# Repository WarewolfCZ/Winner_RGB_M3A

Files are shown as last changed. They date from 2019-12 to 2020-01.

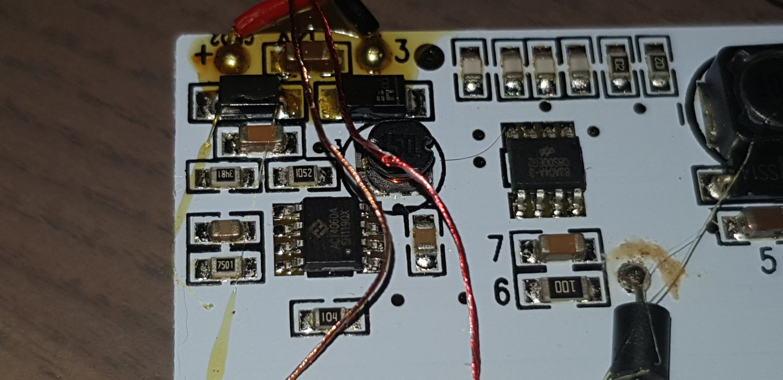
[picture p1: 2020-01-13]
Photo/20191224_005346.jpg

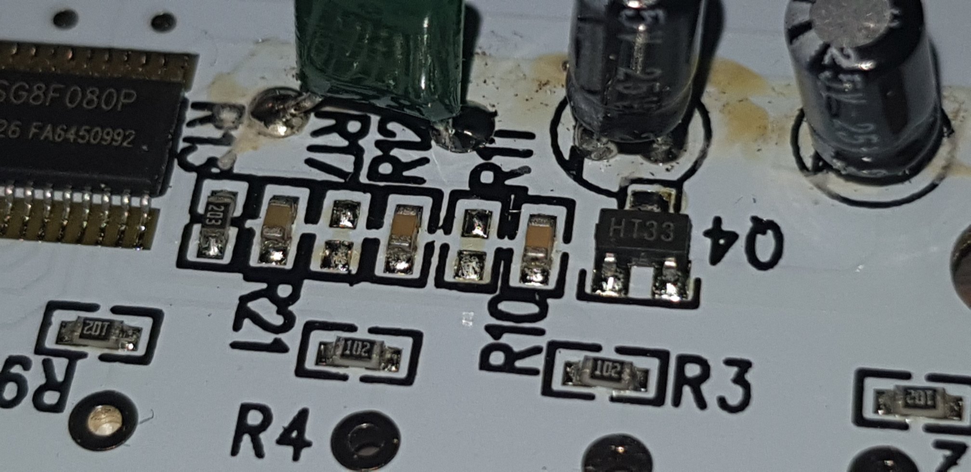
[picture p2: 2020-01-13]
Photo/20191223_173658.jpg

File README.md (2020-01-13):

# Winner_RGB_M3A MOD

This mod board reads lamp status and stores it in EEPROM. When the power is turned off and back on, it is restored to stored state.

## Serial port 

Serial port communication is configured to 19200 baud/s, 8 data bits, even parity

## Protocol

Mod board can be controlled via serial connection/bluetooth. Commands are separated by new line character &lt;CR&gt; or &lt;LF&gt;

### SET

Set lamp state - turn on/off, dim, change light temperature. If cold_level &gt; 0 and warm_level &gt; 0, the cold_level has to be equal to warm_level. 

  SET&lt;COLD_LEVEL&gt;&lt;WARM_LEVEL&gt;

&lt;COLD_LEVEL&gt; = number 0 to 5
&lt;WARM_LEVEL&gt; = number 0 to 5

Example:

  SET11

Response:

  SET_OK:11

### PIN

Set bluetooth pin

  PIN&lt;pin_code&gt;

&lt;pin_code&gt; = 4 digit code

Example:

  PIN0000
  
Response:

  PIN_OK:0000

### STATUS

Get lamp status - light levels

Example:

  STATUS

Response:

  STATUS:&lt;INPUT1&gt;,&lt;INPUT2&gt;,&lt;COLD_LEVEL&gt;,&lt;WARM_LEVEL&gt;,&lt;EEPROM_COLD_LEVEL&gt;,&lt;EEPROM_WARM_LEVEL&gt;

&lt;INPUT1&gt; = value from A/D converter
&lt;INPUT2&gt; = value from A/D converter
&lt;COLD_LEVEL&gt; = number 0 to 5
&lt;WARM_LEVEL&gt; = number 0 to 5
&lt;EEPROM_COLD_LEVEL&gt; = number 0 to 5
&lt;EEPROM_WARM_LEVEL&gt; = number 0 to 5
  
Response example:

  STATUS:0,312,0,2,0,2
  
### DEBUG

Toggle debug mode

Example:

  DEBUG

Response:

  DEBUG_OK

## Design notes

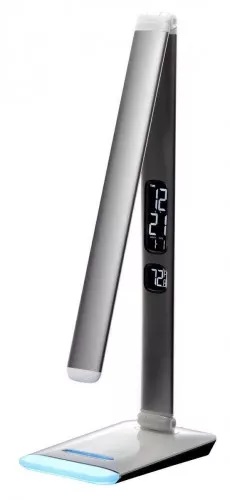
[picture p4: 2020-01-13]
Photo/lamp-led-rgb-m3a.jpg

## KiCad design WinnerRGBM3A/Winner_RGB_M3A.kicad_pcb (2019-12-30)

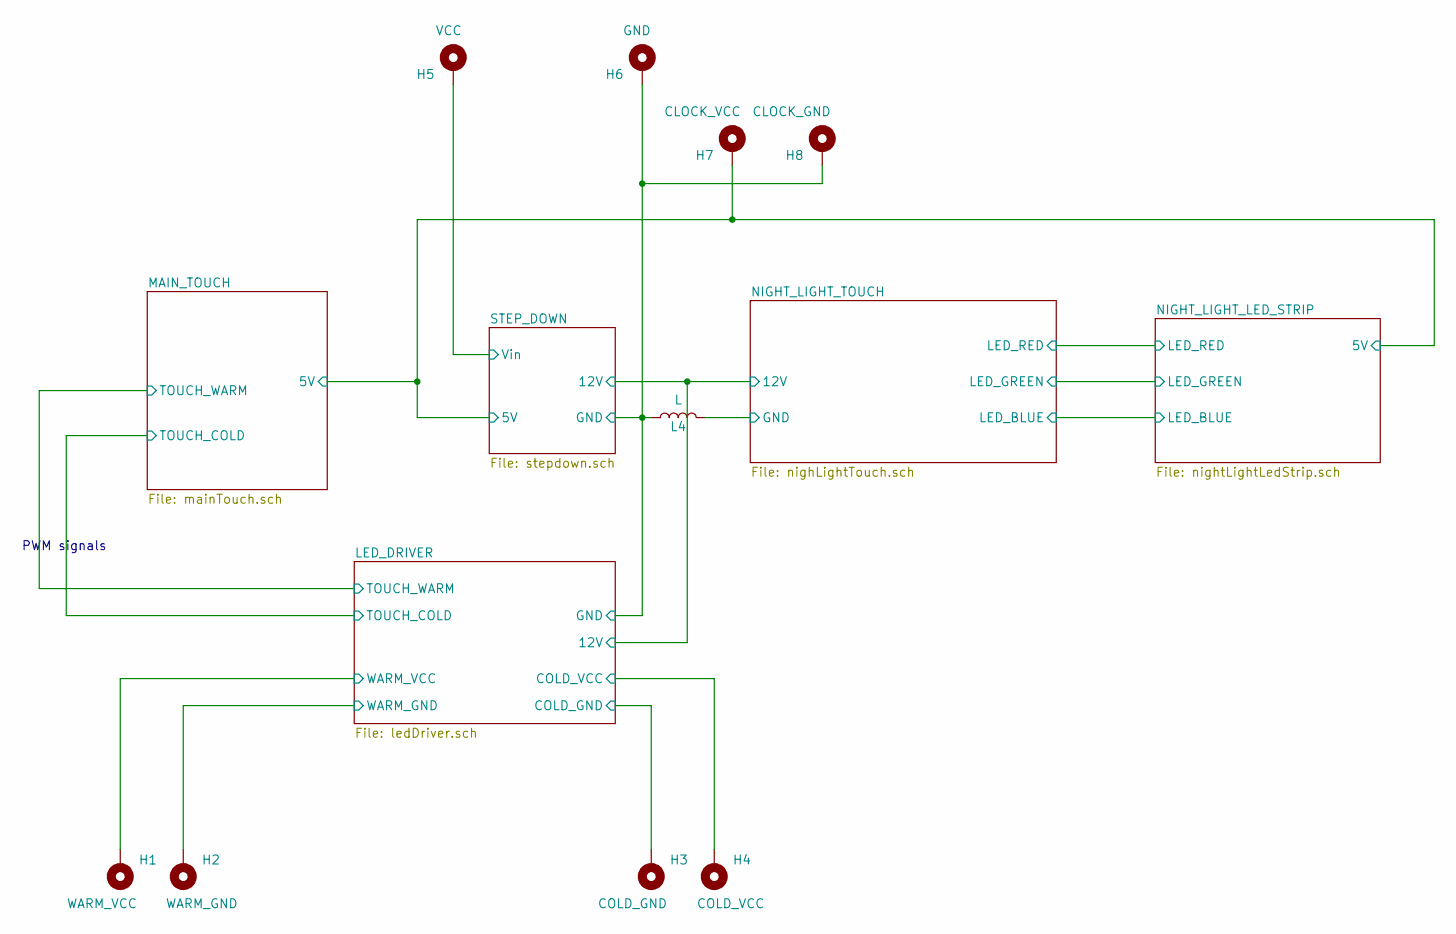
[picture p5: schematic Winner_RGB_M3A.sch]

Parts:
H1: WARM_VCC; Pin_D1.0mm_L10.0mm
H2: WARM_GND; Pin_D1.0mm_L10.0mm
H3: COLD_GND; Pin_D1.0mm_L10.0mm
H4: COLD_VCC; Pin_D1.0mm_L10.0mm
H5: VCC; Pin_D1.0mm_L10.0mm
H6: GND; Pin_D1.0mm_L10.0mm
H7: CLOCK_VCC; Pin_D1.0mm_L10.0mm
H8: CLOCK_GND; Pin_D1.0mm_L10.0mm
L4: L; L_Axial_L14.0mm_D4.5mm_P15.24mm_Horizontal_Fastron_LACC

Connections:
/LED_DRIVER/COLD_GND: H3.1; also elsewhere on the board
/LED_DRIVER/COLD_VCC: H4.1; also elsewhere on the board
/LED_DRIVER/WARM_GND: H2.1; also elsewhere on the board
/LED_DRIVER/WARM_VCC: H1.1; also elsewhere on the board
/MAIN_TOUCH/5V: H7.1; also elsewhere on the board
/NIGHT_LIGHT_TOUCH/GND: L4.2; also elsewhere on the board
/STEP_DOWN/Vin: H5.1; also elsewhere on the board
GNDPWR: H6.1, H8.1, L4.1; also elsewhere on the board

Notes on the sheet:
PWM signals

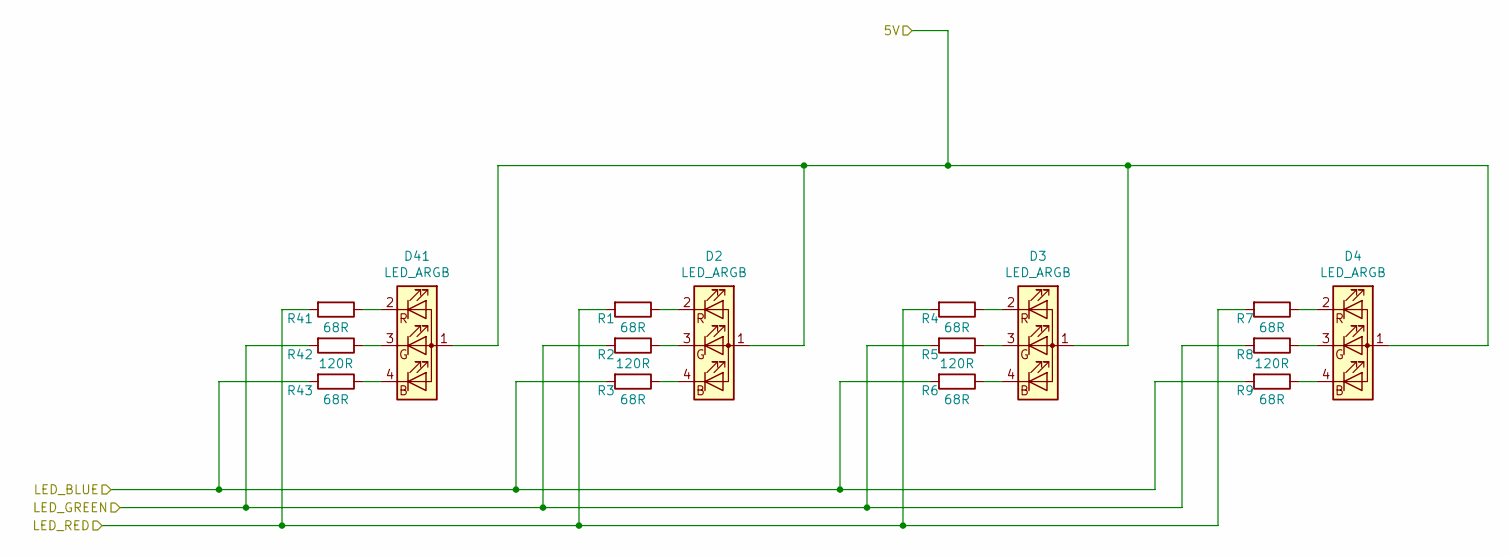
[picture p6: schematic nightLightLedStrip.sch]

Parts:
D2, D3, D4, D41: LED_ARGB; LED_WS2812_PLCC6_5.0x5.0mm_P1.6mm
R1, R3, R4, R6, R7, R9, R41, R43: 68R; R_0805_2012Metric
R2, R5, R8, R42: 120R; R_0805_2012Metric

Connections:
/MAIN_TOUCH/5V: D2.1 (A), D3.1 (A), D4.1 (A), D41.1 (A); also elsewhere on the board
/NIGHT_LIGHT_LED_STRIP/LED_BLUE: R3.2, R6.2, R9.2, R43.2; also elsewhere on the board
/NIGHT_LIGHT_LED_STRIP/LED_GREEN: R2.2, R5.2, R8.2, R42.2; also elsewhere on the board
/NIGHT_LIGHT_LED_STRIP/LED_RED: R1.2, R4.2, R7.2, R41.2; also elsewhere on the board
unnamed: D2.2 (RK), R1.1
unnamed: D2.3 (GK), R2.1
unnamed: D2.4 (BK), R3.1
unnamed: D3.2 (RK), R4.1
unnamed: D3.3 (GK), R5.1
unnamed: D3.4 (BK), R6.1
unnamed: D4.2 (RK), R7.1
unnamed: D4.3 (GK), R8.1
unnamed: D4.4 (BK), R9.1
unnamed: D41.2 (RK), R41.1
unnamed: D41.3 (GK), R42.1
unnamed: D41.4 (BK), R43.1

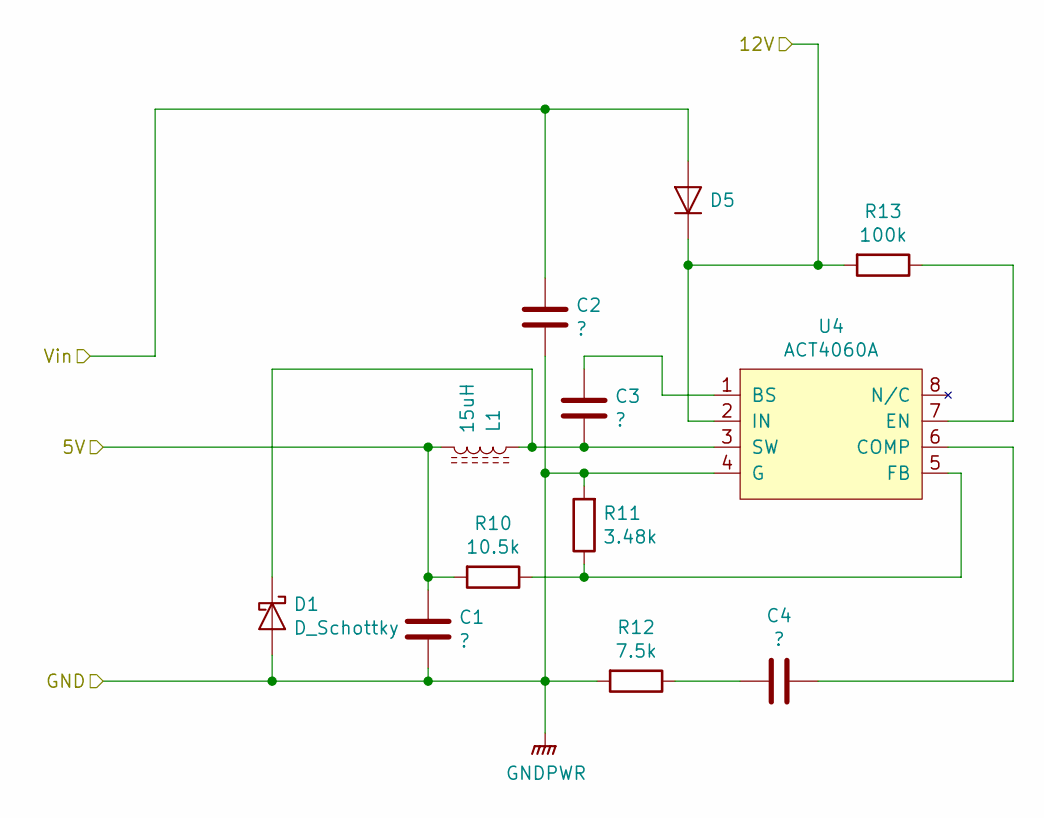
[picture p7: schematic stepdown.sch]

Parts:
C1: ?; C_1206_3216Metric
C2: ?; C_1210_3225Metric
C3, C4: ?; C_0805_2012Metric
D1: D_Schottky; D_2010_5025Metric
D5: D; D_2010_5025Metric
L1: 15uH; L_Wuerth_HCI-5040
R10: 10.5k; R_0805_2012Metric
R11: 3.48k; R_0805_2012Metric
R12: 7.5k; R_0805_2012Metric
R13: 100k; R_0805_2012Metric
U4: ACT4060A; SOP-8_3.76x4.96mm_P1.27mm

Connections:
/LED_DRIVER/12V: D5.1 (K), R13.2, U4.2 (IN); also elsewhere on the board
/MAIN_TOUCH/5V: C1.1, L1.2, R10.2; also elsewhere on the board
/STEP_DOWN/Vin: C2.1, D5.2 (A); also elsewhere on the board
GNDPWR: C1.2, C2.2, D1.2 (A), R11.2, R12.2, U4.4 (G); also elsewhere on the board
unnamed: C3.1, U4.1 (BS)
unnamed: C3.2, D1.1 (K), L1.1, U4.3 (SW)
unnamed: C4.1, U4.6 (COMP)
unnamed: C4.2, R12.1
unnamed: R10.1, R11.1, U4.5 (FB)
unnamed: R13.1, U4.7 (EN)

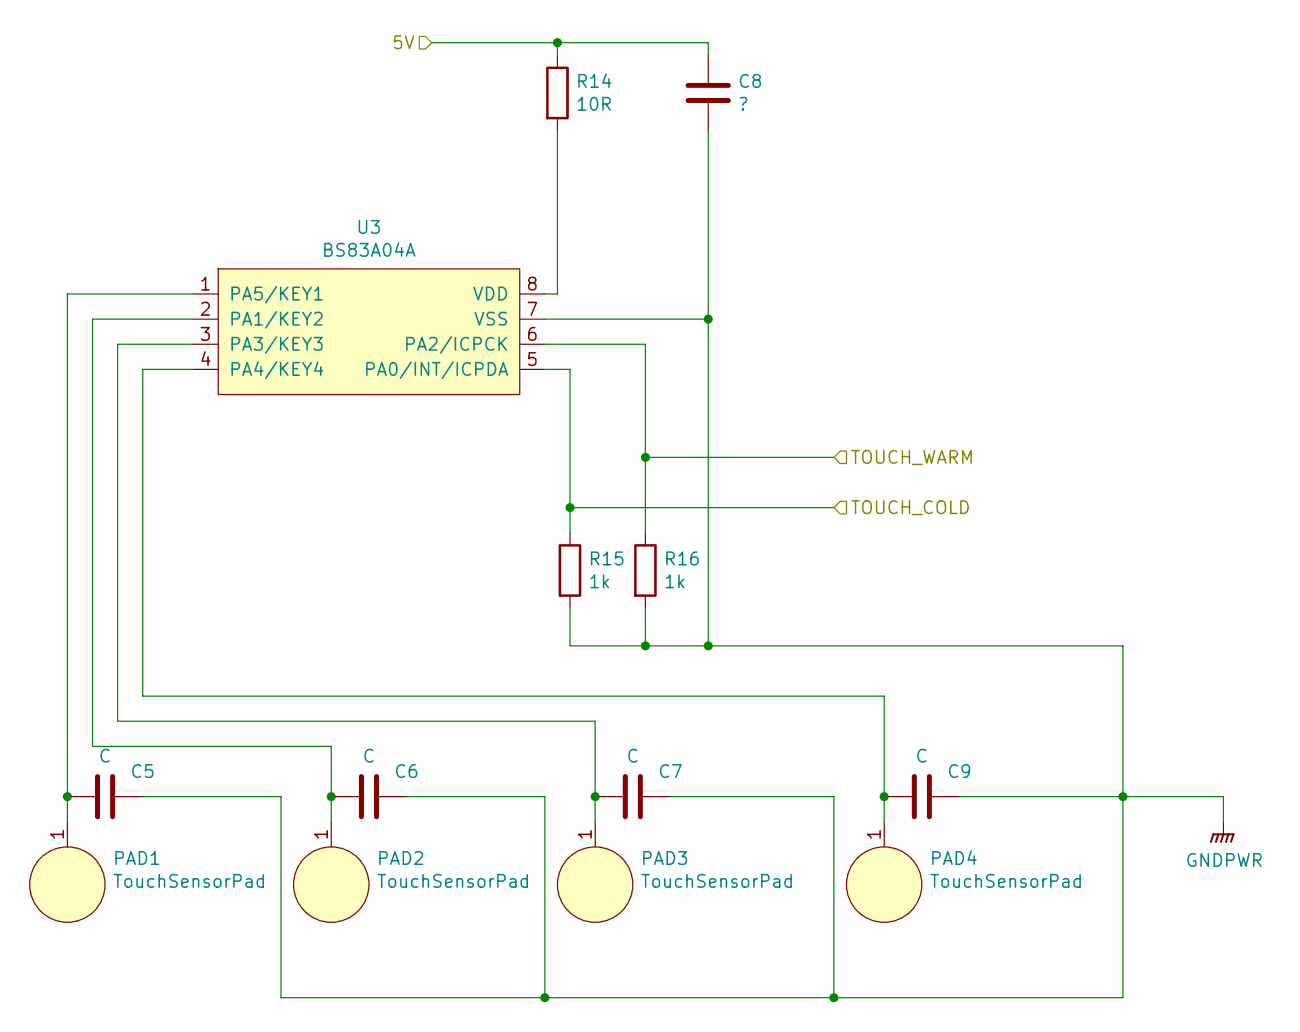
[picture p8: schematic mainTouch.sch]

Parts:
C5, C6, C7, C9: C; C_0805_2012Metric
C8: ?; C_1206_3216Metric
PAD1, PAD2, PAD3, PAD4: TouchSensorPad; Pad_D8.0mm
R14: 10R; R_1206_3216Metric
R15, R16: 1k; R_0805_2012Metric
U3: BS83A04A; SOP-8_3.76x4.96mm_P1.27mm

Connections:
/LED_DRIVER/TOUCH_COLD: R15.1, U3.5 (PA0/INT/ICPDA); also elsewhere on the board
/LED_DRIVER/TOUCH_WARM: R16.1, U3.6 (PA2/ICPCK); also elsewhere on the board
/MAIN_TOUCH/5V: C8.1, R14.1; also elsewhere on the board
GNDPWR: C5.1, C6.1, C7.1, C8.2, C9.1, R15.2, R16.2, U3.7 (VSS); also elsewhere on the board
unnamed: C5.2, PAD1.1, U3.1 (PA5/KEY1)
unnamed: C6.2, PAD2.1, U3.2 (PA1/KEY2)
unnamed: C7.2, PAD3.1, U3.3 (PA3/KEY3)
unnamed: C9.2, PAD4.1, U3.4 (PA4/KEY4)
unnamed: R14.2, U3.8 (VDD)

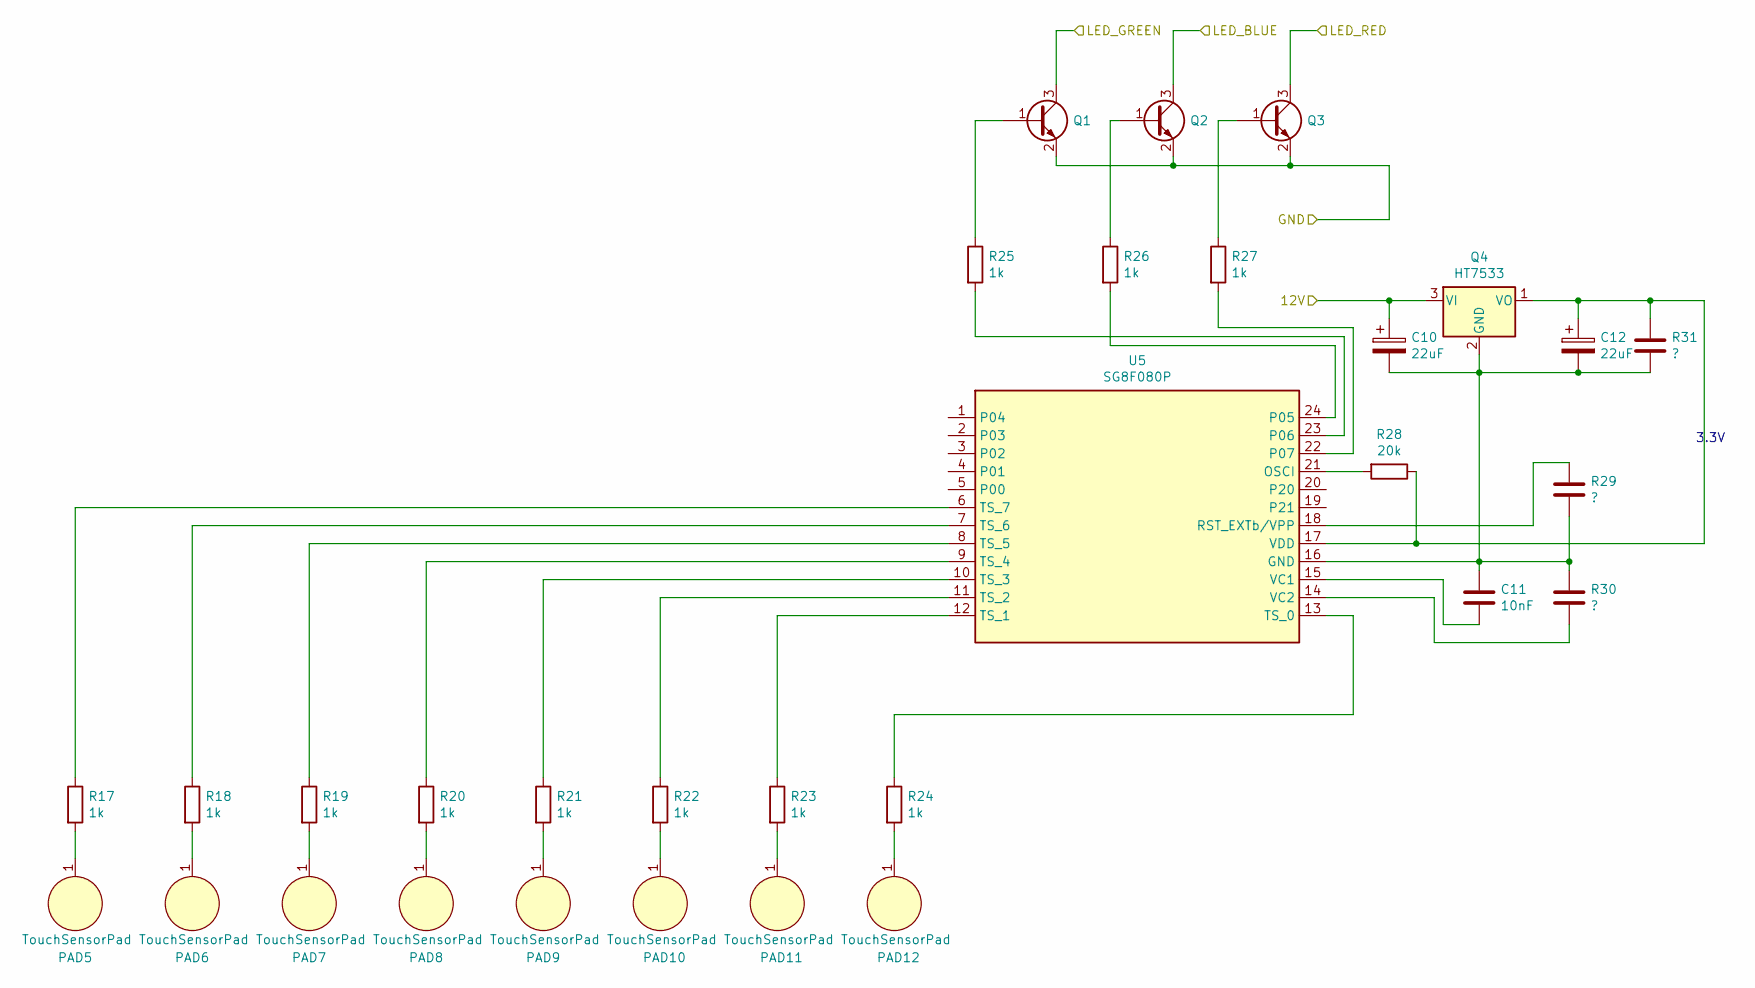
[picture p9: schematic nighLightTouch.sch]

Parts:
C10, C12: 22uF; CP_Radial_D8.0mm_P3.80mm
C11: 10nF; C_Rect_L9.0mm_W2.5mm_P7.50mm_MKT
PAD5, PAD6, PAD7, PAD8, PAD9, PAD10, PAD11, PAD12: TouchSensorPad; Pad_D8.0mm
Q1, Q2, Q3: NPN; SOT-23
Q4: HT7533; SOT-23
R17, R18, R19, R20, R21, R22, R23, R24, R25, R26, R27: 1k; R_0603_1608Metric
R28: 20k; R_0603_1608Metric
R29, R30, R31: ?; C_0603_1608Metric
U5: SG8F080P; TSSOP-24_4.4x7.8mm_P0.65mm

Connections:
/LED_DRIVER/12V: C10.1, Q4.3 (VI); also elsewhere on the board
/NIGHT_LIGHT_LED_STRIP/LED_BLUE: Q2.3 (C); also elsewhere on the board
/NIGHT_LIGHT_LED_STRIP/LED_GREEN: Q1.3 (C); also elsewhere on the board
/NIGHT_LIGHT_LED_STRIP/LED_RED: Q3.3 (C); also elsewhere on the board
/NIGHT_LIGHT_TOUCH/GND: Q1.2 (E), Q2.2 (E), Q3.2 (E); also elsewhere on the board
unnamed: C10.2, C11.1, C12.2, Q4.2 (GND), R29.2, R30.1, R31.2, U5.16 (GND)
unnamed: C11.2, U5.15 (VC1)
unnamed: C12.1, Q4.1 (VO), R28.1, R31.1, U5.17 (VDD)
unnamed: PAD5.1, R17.2
unnamed: PAD6.1, R18.2
unnamed: PAD7.1, R19.2
unnamed: PAD8.1, R20.2
unnamed: PAD9.1, R21.2
unnamed: PAD10.1, R22.2
unnamed: PAD11.1, R23.2
unnamed: PAD12.1, R24.2
unnamed: Q1.1 (B), R25.1
unnamed: Q2.1 (B), R26.1
unnamed: Q3.1 (B), R27.1
unnamed: R17.1, U5.6 (TS_7)
unnamed: R18.1, U5.7 (TS_6)
unnamed: R19.1, U5.8 (TS_5)
unnamed: R20.1, U5.9 (TS_4)
unnamed: R21.1, U5.10 (TS_3)
unnamed: R22.1, U5.11 (TS_2)
unnamed: R23.1, U5.12 (TS_1)
unnamed: R24.1, U5.13 (TS_0)
unnamed: R25.2, U5.23 (P06)
unnamed: R26.2, U5.24 (P05)
unnamed: R27.2, U5.22 (P07)
unnamed: R28.2, U5.21 (OSCI)
unnamed: R29.1, U5.18 (RST_EXTb/VPP)
unnamed: R30.2, U5.14 (VC2)

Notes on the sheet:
3.3V

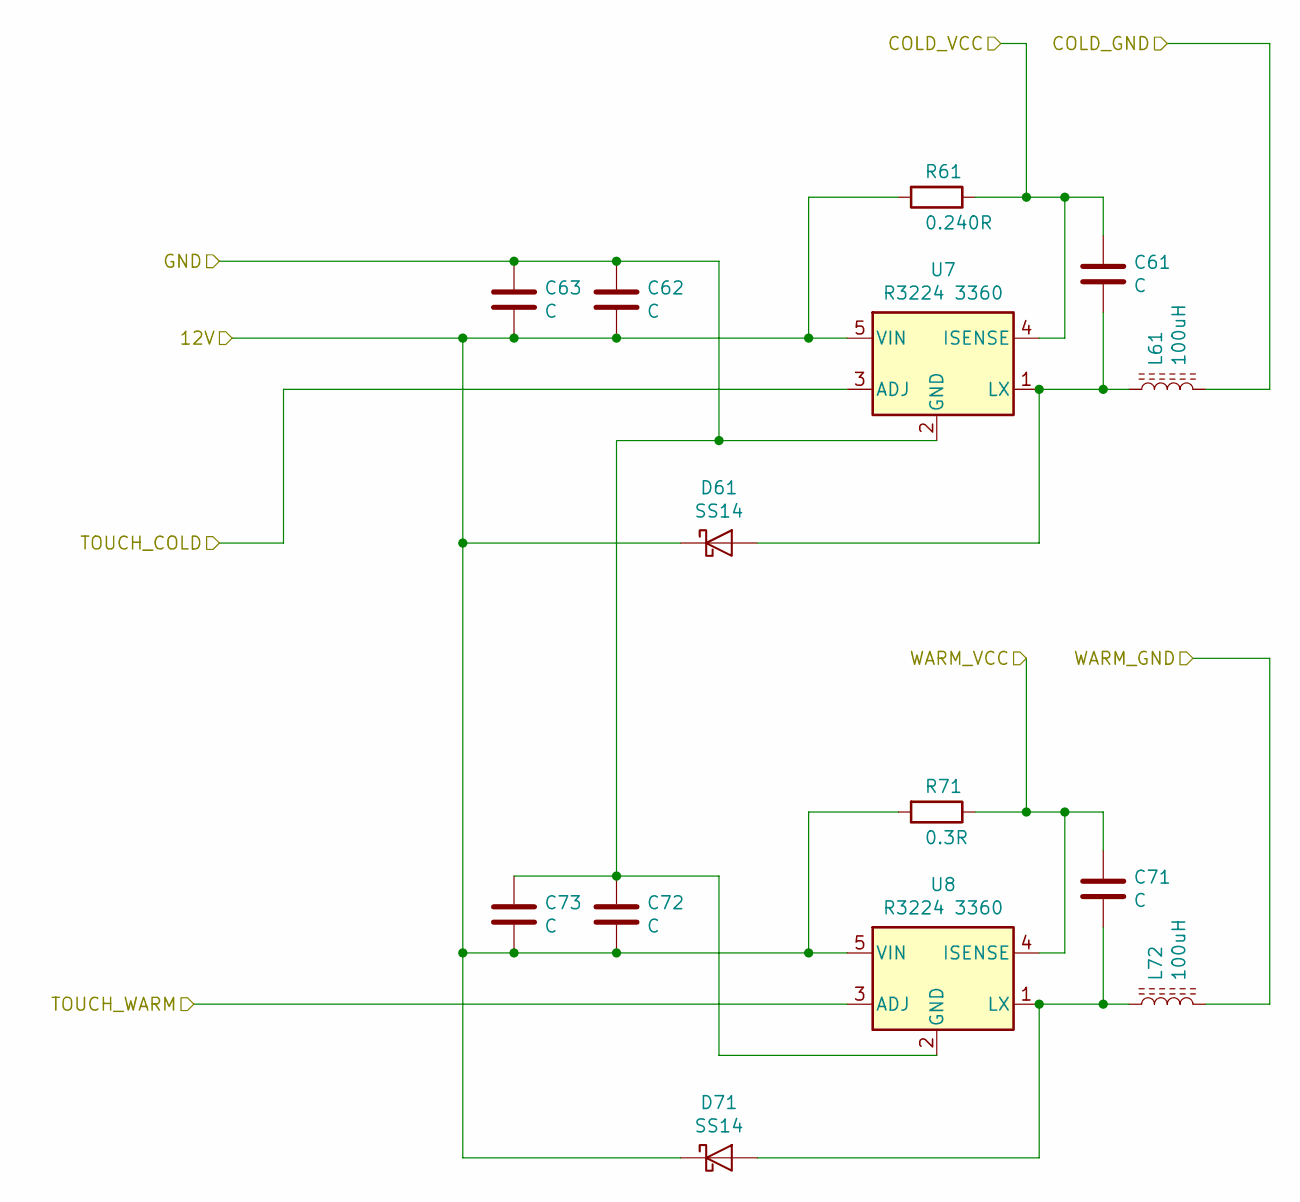
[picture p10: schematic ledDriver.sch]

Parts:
C61, C62, C71, C72: C; C_0805_2012Metric
C63, C73: C; C_1206_3216Metric
D61, D71: SS14; D_SMA
L61, L72: 100uH; L_7.3x7.3_H4.5
R61: 0.240R; R_0805_2012Metric
R71: 0.3R; R_0805_2012Metric
U7, U8: R3224 3360; TSOT-23-5

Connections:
/LED_DRIVER/12V: C62.2, C63.2, C72.2, C73.2, D61.1 (K), D71.1 (K), R61.2, R71.2, U7.5 (VIN), U8.5 (VIN); also elsewhere on the board
/LED_DRIVER/COLD_GND: L61.2; also elsewhere on the board
/LED_DRIVER/COLD_VCC: C61.1, R61.1, U7.4 (ISENSE); also elsewhere on the board
/LED_DRIVER/TOUCH_COLD: U7.3 (ADJ); also elsewhere on the board
/LED_DRIVER/TOUCH_WARM: U8.3 (ADJ); also elsewhere on the board
/LED_DRIVER/WARM_GND: L72.2; also elsewhere on the board
/LED_DRIVER/WARM_VCC: C71.1, R71.1, U8.4 (ISENSE); also elsewhere on the board
GNDPWR: C62.1, C63.1, C72.1, C73.1, U7.2 (GND), U8.2 (GND); also elsewhere on the board
unnamed: C61.2, D61.2 (A), L61.1, U7.1 (LX)
unnamed: C71.2, D71.2 (A), L72.1, U8.1 (LX)

Board: 2 copper layers, 95 parts (12 on the bottom side), 67 nets, no tracks yet.

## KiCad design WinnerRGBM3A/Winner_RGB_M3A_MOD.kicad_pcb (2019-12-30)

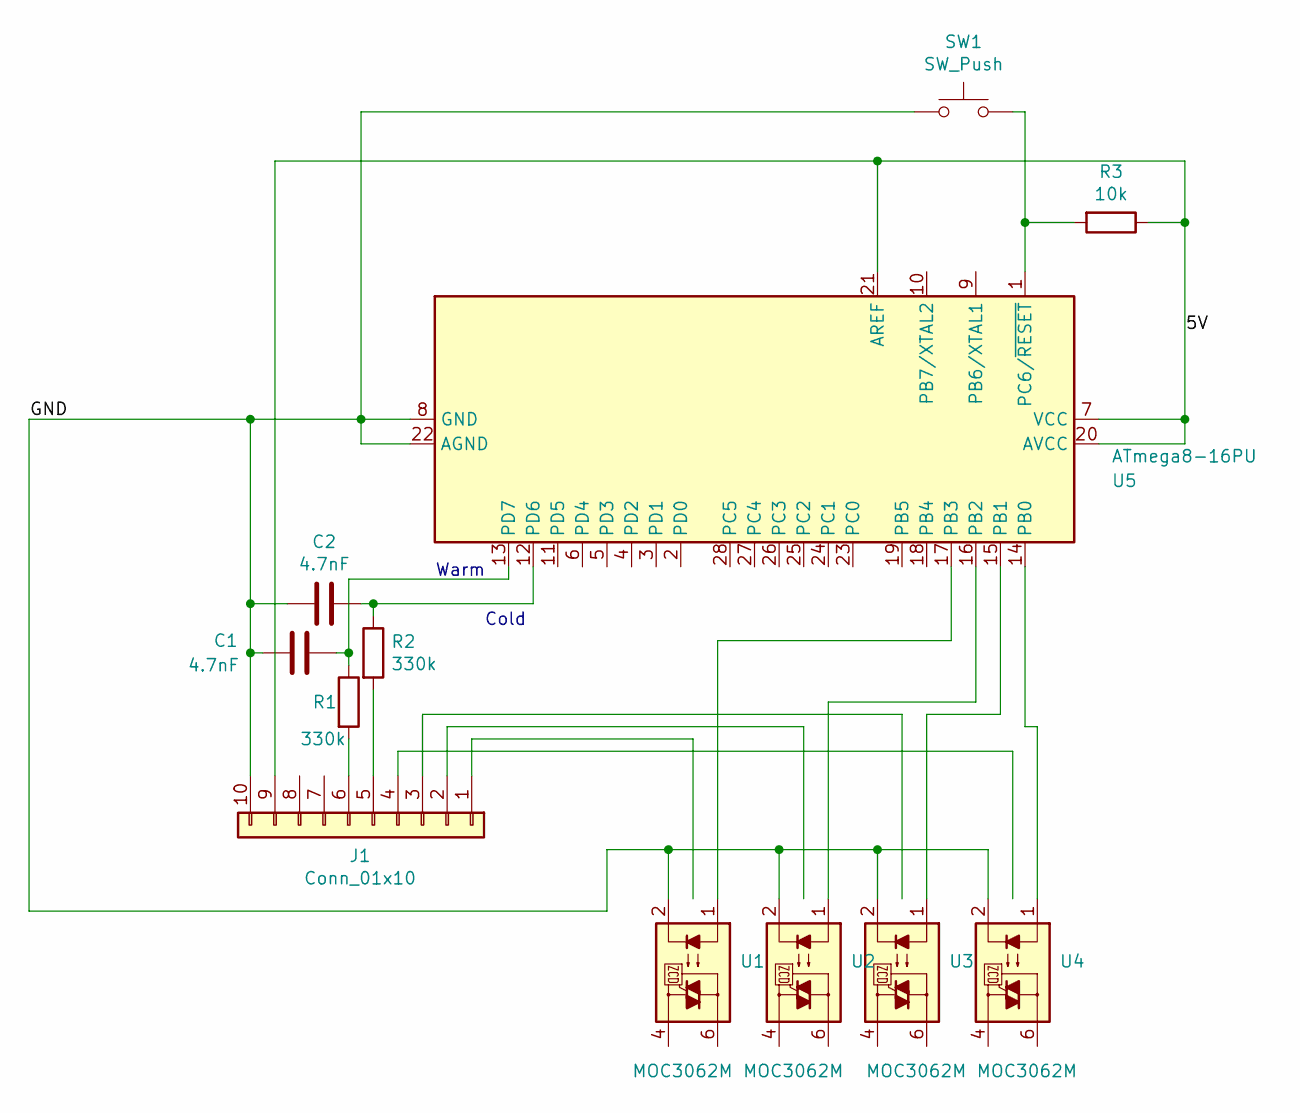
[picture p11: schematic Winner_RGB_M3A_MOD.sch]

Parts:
C1, C2: 4.7nF; C_Disc_D5.0mm_W2.5mm_P5.00mm
J1: Conn_01x10; JST_PH_S10B-PH-K_1x10_P2.00mm_Horizontal
R1, R2: 330k; R_Axial_DIN0207_L6.3mm_D2.5mm_P7.62mm_Horizontal
R3: 10k; R_Axial_DIN0207_L6.3mm_D2.5mm_P7.62mm_Horizontal
SW1: SW_Push; SW_PUSH_6mm_H5mm
U1, U2, U3, U4: MOC3062M; DIP-6_W7.62mm
U5: ATmega8-16PU; DIP-28_W7.62mm

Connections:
/5V: J1.9, R3.1, U5.7 (VCC), U5.20 (AVCC), U5.21 (AREF)
/GND: C1.2, C2.2, J1.10, SW1.1, U1.2, U2.2, U3.2, U4.2, U5.8 (GND), U5.22 (AGND)
unnamed: C1.1, R1.1, U5.13 (PD7)
unnamed: C2.1, R2.1, U5.12 (PD6)
unnamed: J1.1, U1.3 (NC)
unnamed: J1.2, U2.3 (NC)
unnamed: J1.3, U3.3 (NC)
unnamed: J1.4, U4.3 (NC)
unnamed: J1.5, R2.2
unnamed: J1.6, R1.2
unnamed: R3.2, SW1.2, U5.1 (PC6/~RESET)
unnamed: U1.1, U5.17 (PB3)
unnamed: U2.1, U5.16 (PB2)
unnamed: U3.1, U5.15 (PB1)
unnamed: U4.1, U5.14 (PB0)

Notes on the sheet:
Cold
Warm

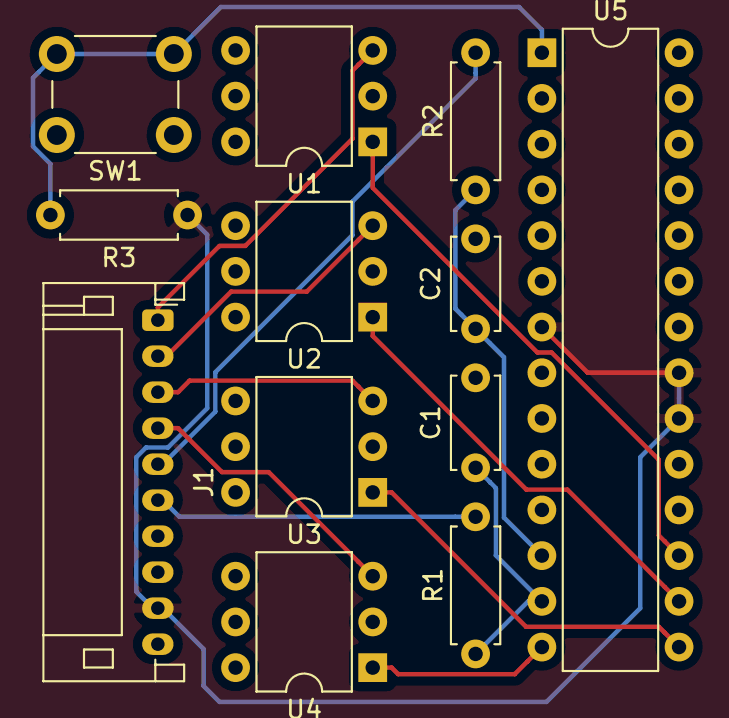
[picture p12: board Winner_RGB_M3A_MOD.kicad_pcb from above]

Board: 2 copper layers, 12 parts (0 on the bottom side), 15 nets.

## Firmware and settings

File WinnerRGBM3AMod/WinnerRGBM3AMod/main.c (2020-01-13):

/*
 * WinnerRGBM3AMod.c
 *
 * Created: 25.12.2019 15:36:18
 * Author : WarewolfCZ
 */ 

#define VERSION "1.0.0"

#define F_CPU 8000000UL // 8 MHz
#define BAUD 19200       // define speed
#define BAUDRATE ((F_CPU)/(BAUD*16UL)-1) // set baud rate value for UBRR
#define DEFAULT_LED_TIMER_THRESHOLD 40
#define EEPROM_SETTINGS_ADDRESS 0x00
#define EEPROM_SETTINGS_DEBUG 0x04
#define ANALOG_INPUTS_COUNT 6
#define OUTPUTS_COUNT 4
#define INPUT_COLD 0
#define INPUT_WARM 1

#define OUTPUT_POWER 3
#define OUTPUT_MODE 2
#define OUTPUT_INCREASE 1
#define OUTPUT_DECREASE 0

#define LEVEL_1_THRESHOLD 90 // 0 to 135
#define LEVEL_2_THRESHOLD 250 // 135 to 315
#define LEVEL_3_THRESHOLD 600 // 315 to 665
#define LEVEL_4_THRESHOLD 800 // 665 to 840
#define LEVEL_5_THRESHOLD 930 // 840 to 965

#define LEVEL_0 0
#define LEVEL_1 1
#define LEVEL_2 2
#define LEVEL_3 3
#define LEVEL_4 4
#define LEVEL_5 5

#define SETTINGS_COLD ((uint8_t)(settings >> 8))
#define SETTINGS_WARM ((uint8_t)(settings & 0xFF))

#define POWER_DIFFERS ((inputs[INPUT_COLD] == LEVEL_0 && inputs[INPUT_WARM] == LEVEL_0 && (SETTINGS_COLD != LEVEL_0 || SETTINGS_WARM != LEVEL_0)) || ((inputs[INPUT_COLD] != LEVEL_0 || inputs[INPUT_WARM] != LEVEL_0) && SETTINGS_COLD == LEVEL_0 && SETTINGS_WARM == LEVEL_0))
#define MODE_DIFFERS (\
 (inputs[INPUT_COLD] == LEVEL_0 && SETTINGS_COLD != LEVEL_0) ||\
 (inputs[INPUT_WARM] == LEVEL_0 && SETTINGS_WARM != LEVEL_0) ||\
 (inputs[INPUT_COLD] != LEVEL_0 && SETTINGS_COLD == LEVEL_0) ||\
 (inputs[INPUT_WARM] != LEVEL_0 && SETTINGS_WARM == LEVEL_0)\
)
#define BRIGHTNESS_DIFFERS (inputs[INPUT_COLD] != SETTINGS_COLD || inputs[INPUT_WARM] != SETTINGS_WARM)

#define COLD_BRIGHTNESS_LOWER (inputs[INPUT_COLD] < SETTINGS_COLD)
#define WARM_BRIGHTNESS_LOWER (inputs[INPUT_WARM] < SETTINGS_WARM)

#define COLD_BRIGHTNESS_HIGHER (inputs[INPUT_COLD] > SETTINGS_COLD)
#define WARM_BRIGHTNESS_HIGHER (inputs[INPUT_WARM] > SETTINGS_WARM)

#define BRIGHTNESS_LOWER COLD_BRIGHTNESS_LOWER || WARM_BRIGHTNESS_LOWER
#define BRIGHTNESS_HIGHER COLD_BRIGHTNESS_HIGHER || WARM_BRIGHTNESS_HIGHER

#define TOUCH_DELAY 150

#include <avr/io.h>
#include <util/delay.h>
#include <stdlib.h>
//#include <stdio.h>
#include <string.h>
#include <avr/wdt.h>
#include <avr/eeprom.h>
#include <avr/pgmspace.h>

uint16_t settings;
uint8_t pin[4];
uint8_t debugMode;
uint8_t selectedInput = 0;
uint16_t analogInputs[ANALOG_INPUTS_COUNT];
uint8_t inputs[ANALOG_INPUTS_COUNT];
uint8_t bufferIndex = 0;
uint8_t bufferLimit = 9;
char uartBuffer[10];


// function to initialize UART
void uart_init (void) {
	UBRRH = (BAUDRATE>>8);                      // shift the register right by 8 bits
	UBRRL = BAUDRATE;                           // set baud rate
	UCSRB|= (1<<TXEN)|(1<<RXEN);                // enable receiver and transmitter
	UCSRC|= (1<<URSEL)|(1<<UPM1)|(1<<UCSZ0)|(1<<UCSZ1);   // 8bit data format, even parity
	
	DDRD |= 1 << PIND1;//pin1 of portD as OUTPUT
	DDRD &= ~(1 << PIND0);//pin0 of portD as INPUT
	PORTD |= 1 << PIND0; // turn on the pull-up
}

// function to send data
void uart_transmit (unsigned char data) {
	while ( !( UCSRA & (1<<UDRE)) );              // wait while register is free
	UDR = data;                                   // load data in the register
}

// function to receive data
unsigned char uart_receive (void) {
	while(!(UCSRA & (1<<RXC)));                   // wait while data is being received
	return UDR;                                   // return 8-bit data
}

void uart_str_transmit(char* str) {
	int i = 0;
	
	while (str[i] != 0x00) {
		uart_transmit(str[i]);
		i++;
	}
}

/************************************************************************/
/* Send string from program memory                                      */
/************************************************************************/
void uart_prg_str_transmit(const char str[]) {

    uint8_t c;
    while (0 != (c = pgm_read_byte(str++))) {
        uart_transmit(c);
    }
}

char* flushBuffer() {
    uartBuffer[bufferIndex] = 0x00;
    bufferIndex = 0;
    return uartBuffer;
}

char* uart_str_receive() {
    if (bufferIndex == 0) {
        memset(uartBuffer, 0, sizeof(uartBuffer[0])*bufferLimit); // clear buffer
    }
	if (bufferIndex < bufferLimit) {
		unsigned char receivedChar = uart_receive();
        if (receivedChar == '\n' || receivedChar == '\r') {
            return flushBuffer();
        } else {
		    uartBuffer[bufferIndex] = receivedChar;
            bufferIndex++;
            //uart_transmit(receivedChar);
        }
	} else {
        return flushBuffer();
    }
	return NULL;
}

void wdt_init(void) {
	MCUSR = 0;
	wdt_disable(); //disable watchdog
}

void soft_reset() {
    if (debugMode) uart_prg_str_transmit(PSTR("Soft reset\r\n"));
    // enable watchdog and let it reset the controller
    wdt_enable(WDTO_15MS);
    for(;;){}
}

void adc_init() {
    ADCSRA |= (1 << ADEN); // enable ADC
    ADMUX &= ~((1 << REFS1) | (1 << REFS0)); // select voltage reference - AREF
    ADMUX |= 0; // select pin ADC0 as analog input
    ADCSRA |= (1 << ADPS2) | (1 << ADPS1); // use a prescaler of 64
}

void output_init() {
    DDRB |= 1 << PINB0; // PIN0 of portB as OUTPUT
    DDRB |= 1 << PINB1; // PIN1 of portB as OUTPUT
    DDRB |= 1 << PINB2; // PIN3 of portB as OUTPUT
    DDRB |= 1 << PINB3; // PIN3 of portB as OUTPUT
    PORTB &= ~(1 << PINB0); // set PB0 to LOW
    PORTB &= ~(1 << PINB1); // set PB1 to LOW
    PORTB &= ~(1 << PINB2); // set PB2 to LOW
    PORTB &= ~(1 << PINB3); // set PB3 to LOW
}

void touchPower() {
    if (debugMode) uart_prg_str_transmit(PSTR("power button touch\r\n"));
    PORTB |= (1 << PINB3);
    _delay_ms(200);
    PORTB &= ~(1 << PINB3);
    _delay_ms(TOUCH_DELAY);
}

void touchMode() {
    if (debugMode) uart_prg_str_transmit(PSTR("mode button touch\r\n"));
    PORTB |= (1 << PINB2);
    _delay_ms(TOUCH_DELAY);
    PORTB &= ~(1 << PINB2);
    _delay_ms(TOUCH_DELAY);
}

void touchIncrease() {
    if (debugMode) uart_prg_str_transmit(PSTR("increase button touch\r\n"));
    PORTB |= (1 << PINB1);
    _delay_ms(TOUCH_DELAY);
    PORTB &= ~(1 << PINB1);
    _delay_ms(TOUCH_DELAY);
}

void touchDecrease() {
    if (debugMode) uart_prg_str_transmit(PSTR("decrease button touch\r\n"));
    PORTB |= (1 << PINB0); // set PB0 to HIGH
    _delay_ms(TOUCH_DELAY);
    PORTB &= ~(1 << PINB0); // set PB0 to LOW
    _delay_ms(TOUCH_DELAY);
}

uint16_t validateSettings() {
    if (settings == 0xFFFF || SETTINGS_COLD > LEVEL_5 || SETTINGS_WARM > LEVEL_5 || 
    (SETTINGS_COLD != 0 && SETTINGS_WARM != 0 && SETTINGS_COLD != SETTINGS_WARM)) {
        if (debugMode) uart_prg_str_transmit(PSTR("Clearing invalid settings\r\n"));
        settings = 0;
    }
    return settings;
}

void updateSettings(uint16_t settings) {
    uint16_t oldValue = eeprom_read_word(EEPROM_SETTINGS_ADDRESS);
    settings = validateSettings();
    eeprom_update_word(EEPROM_SETTINGS_ADDRESS, settings);
    if (settings != oldValue) {
        if (debugMode) {
            uart_prg_str_transmit(PSTR("Settings written to EEPROM: 0x0"));
            uart_transmit(SETTINGS_COLD + '0');
            uart_transmit('0');
            uart_transmit(SETTINGS_WARM + '0');
            uart_prg_str_transmit(PSTR("\r\n"));
        }
    }
}

uint16_t readSettings() {
    settings = eeprom_read_word(EEPROM_SETTINGS_ADDRESS);
    if (settings == 0xFFFF || SETTINGS_COLD > LEVEL_5 || SETTINGS_WARM > LEVEL_5) {
        uart_prg_str_transmit(PSTR("Initializing EEPROM\r\n"));
        settings = 0;
        updateSettings(settings);
    }
    return settings;
}


void sendLoadedSettings() {
    uart_prg_str_transmit(PSTR("Settings loaded from EEPROM: 0x0"));
    uart_transmit(SETTINGS_COLD + '0');
    uart_transmit('0');
    uart_transmit(SETTINGS_WARM + '0');
    uart_prg_str_transmit(PSTR("\r\n"));
}

void updateDebugMode(uint8_t debugMode) {
    if (debugMode > 0) debugMode = 1;
    else debugMode = 0;
    uint8_t oldValue = eeprom_read_byte(EEPROM_SETTINGS_DEBUG);
    eeprom_update_byte(EEPROM_SETTINGS_DEBUG, debugMode);
    if (debugMode != oldValue) {
        uart_prg_str_transmit(PSTR("Debug mode written to EEPROM: 0x"));
        uart_transmit(debugMode + '0');
        uart_prg_str_transmit(PSTR("\r\n"));
    }
}

uint16_t readDebugMode() {
    debugMode = eeprom_read_byte(EEPROM_SETTINGS_DEBUG);
    if (debugMode == 0xFF) {
        uart_prg_str_transmit(PSTR("Initializing debugMode mode value\r\n"));
        debugMode = 0;
        updateDebugMode(debugMode);
    }
    return debugMode;
}

void sendLoadedDebugMode() {
    uart_prg_str_transmit(PSTR("Debug mode loaded from EEPROM: 0x0"));
    uart_transmit(debugMode + '0');
    uart_prg_str_transmit(PSTR("\r\n"));
}

uint8_t getInputLevel(uint16_t input) {
    if (input < LEVEL_1_THRESHOLD) {
        return LEVEL_0;
    } else if (input < LEVEL_2_THRESHOLD) {
        return LEVEL_1;
    } else if (input < LEVEL_3_THRESHOLD) {
        return LEVEL_2;
    } else if (input < LEVEL_4_THRESHOLD) {
        return LEVEL_3;
    } else if (input < LEVEL_5_THRESHOLD) {
        return LEVEL_4;
    } else {
        return LEVEL_5;
    }
}

void readInputs() {
    for (int i = 0; i < ANALOG_INPUTS_COUNT; i++) {
        ADMUX = (((1 << REFS1) | (1 << REFS0)) & 0xFF) + selectedInput; // select input pin
        ADCSRA |= (1 << ADSC);  // start conversion
        while (ADCSRA & (1<<ADSC)); //wait for conversion to finish
        uint16_t value = 0;
        value = ADCL;
        value |= (ADCH << 8);
        analogInputs[selectedInput] = value;
        inputs[selectedInput] = getInputLevel(value);
        selectedInput++;
        selectedInput = selectedInput % ANALOG_INPUTS_COUNT;
    }
}

void sendStatus() {
    char msg[5];
    uart_prg_str_transmit(PSTR("STATUS:"));
    itoa(analogInputs[0], msg, 10);
    uart_str_transmit(msg);
    uart_transmit(',');
    itoa(analogInputs[1], msg, 10);
    uart_str_transmit(msg);
    uart_transmit(',');

    itoa(inputs[INPUT_COLD], msg, 10);
    uart_str_transmit(msg);
    uart_transmit(',');
    itoa(inputs[INPUT_WARM], msg, 10);
    uart_str_transmit(msg);
    uart_transmit(',');

    itoa(SETTINGS_COLD, msg, 10);
    uart_str_transmit(msg);
    uart_transmit(',');
    itoa(SETTINGS_WARM, msg, 10);
    uart_str_transmit(msg);

    uart_prg_str_transmit(PSTR("\r\n"));

    if (debugMode) {
        uart_prg_str_transmit(PSTR("Buffer status: index: "));
        itoa(bufferIndex, msg, 10);
        uart_str_transmit(msg);
        uart_prg_str_transmit(PSTR(", limit: "));
        itoa(bufferLimit, msg, 10);
        uart_str_transmit(msg);
        uart_prg_str_transmit(PSTR(", buffer content: "));
        uart_str_transmit(uartBuffer);
        uart_prg_str_transmit(PSTR("\r\n"));
    }
}


void setup() {

    readInputs();
    uint8_t counter = 0;
    _delay_ms(500);
    validateSettings();
    while (POWER_DIFFERS) {
        if (debugMode) uart_prg_str_transmit(PSTR("Power status differs\r\n"));
        if (debugMode) sendStatus();
        touchPower();
        readInputs();
        counter++;
        if (counter > 10) soft_reset();
    }
    counter = 0;
    _delay_ms(50);
    while (MODE_DIFFERS) {
        if (debugMode) uart_prg_str_transmit(PSTR("Mode differs\r\n"));
        if (debugMode) sendStatus();
        touchMode();
        readInputs();
        counter++;
        if (counter > 10) soft_reset();
    }
    _delay_ms(50);
    counter = 0;
    while (BRIGHTNESS_DIFFERS) {
        if (debugMode) uart_prg_str_transmit(PSTR("Brightness differs\r\n"));
        if (debugMode) sendStatus();
        counter = 0;
        while (BRIGHTNESS_LOWER) {
            touchIncrease();
            if (debugMode) sendStatus();
            readInputs();
            counter++;
            if (counter > 10) soft_reset();
        }
        counter = 0;
        while (BRIGHTNESS_HIGHER) {
            touchDecrease();
            if (debugMode) sendStatus();
            readInputs();
            counter++;
            if (counter > 10) soft_reset();
        }
    }
}


int main(void) {
	wdt_init(); // disable watchdog
    output_init();
    adc_init();
	uart_init();

    uint16_t statusCounter = 0;
    uint16_t settingsCounter = 0;
    ADCSRA |= (1 << ADSC);  // start ADC conversion
    readSettings();
    readDebugMode();
    uart_prg_str_transmit(PSTR("======= Winner RGB M3A Lamp mod v"));
    uart_prg_str_transmit(PSTR(VERSION));
    uart_prg_str_transmit(PSTR(" by WarewolfCZ =======\r\n"));
    uart_prg_str_transmit(PSTR("Supported commands:\r\n"));
    uart_prg_str_transmit(PSTR("SETXY = set light levels, X = cold Y = warm, X and Y in interval <0,5>\r\n"));
    uart_prg_str_transmit(PSTR("PINXXXX = set Bluetooth PIN\r\n"));
    uart_prg_str_transmit(PSTR("STATUS = request status line\r\n"));
    uart_prg_str_transmit(PSTR("DEBUG = toggle debug mode\r\n"));
    uart_prg_str_transmit(PSTR("Commands are separated by new line\r\n\r\n"));

    if (debugMode) sendLoadedSettings();
    if (debugMode) sendLoadedDebugMode();
    _delay_ms(50);
    setup();
    uart_prg_str_transmit(PSTR("Setup complete\r\n"));

	while (1) { 
        if (UCSRA & (1<<RXC)) {
            char* data = uart_str_receive();
            if (data != NULL && data[0] != 0x00) {
                if (debugMode)  {
                    uart_prg_str_transmit(PSTR("RECEIVED:"));
                    uart_str_transmit(data);
                    uart_prg_str_transmit(PSTR("\r\n"));
                }

                if (strncasecmp(data, "SET", 3) == 0 && strlen(data) >= 5) {
                    uint8_t cold = ((data[3] - '0') % (LEVEL_5 + 1));
                    uint8_t warm = ((data[4] - '0') % (LEVEL_5 + 1));
                    if (cold != warm && cold != 0 && warm != 0) { // invalid combination, set both to same value
                        uart_prg_str_transmit(PSTR("SET_INVALID:"));
                    } else {
                        settings = cold << 8 | warm;
                        uart_prg_str_transmit(PSTR("SET_OK:"));
                    }
                    uart_transmit((unsigned char) cold + '0');
                    uart_transmit((unsigned char) warm + '0');
                    uart_prg_str_transmit(PSTR("\r\n"));
                    updateSettings(settings);
                    setup();
                } else if (strncasecmp(data, "PIN", 3) == 0 && strlen(data) >= 7) {
                    pin[0] = ((data[3] - '0') % 10);
                    pin[1] = ((data[4] - '0') % 10);
                    pin[2] = ((data[5] - '0') % 10);
                    pin[3] = ((data[6] - '0') % 10);
                    uart_prg_str_transmit(PSTR("PIN_OK:"));
                    uart_transmit((unsigned char) (pin[0] + '0'));
                    uart_transmit((unsigned char) (pin[1] + '0'));
                    uart_transmit((unsigned char) (pin[2] + '0'));
                    uart_transmit((unsigned char) (pin[3] + '0'));
                    uart_prg_str_transmit(PSTR("\r\n"));
                    setup();
                } else if (strncasecmp(data, "STATUS", 6) == 0) {
                    sendStatus();
                } else if (strncasecmp(data, "DEBUG", 5) == 0) {
                    if (debugMode > 0) debugMode = 0;
                    else debugMode = 1;
                    uart_prg_str_transmit(PSTR("DEBUG_OK\r\n"));
                    updateDebugMode(debugMode);
                } else {
                    uart_prg_str_transmit(PSTR("CMD_INVALID\r\n"));
                }
            }
        }
        readInputs();
        statusCounter++;
        statusCounter = statusCounter % 9000;
        settingsCounter++;
        settingsCounter = settingsCounter % 1000;
        
        if (MODE_DIFFERS || BRIGHTNESS_DIFFERS) {    
            settings = (((uint16_t) inputs[INPUT_COLD]) << 8) | inputs[INPUT_WARM];
        }
        
        if (debugMode && statusCounter == 0) {
            sendStatus();
        }
        if (settingsCounter == 0) {
            updateSettings(settings);
        }
	}
}

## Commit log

2019-12-30 files added
    [Winner_RGB_M3A.kicad_pcb, Winner_RGB_M3A.sch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]
2020-01-13 changed project structure
    [Winner_RGB_M3A.kicad_pcb, Winner_RGB_M3A.sch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]
